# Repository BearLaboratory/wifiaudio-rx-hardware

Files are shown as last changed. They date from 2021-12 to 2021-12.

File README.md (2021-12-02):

<h1 align="center" style="font-size:50px;font-weight:bold">WiFiAudio</h1>
<p align="center">基于WiFi的语音传输系统</p>
<p align="center">
    <a href="https://github.com/">
        
    </a>
    <a href="">
        
    </a> 
    <a href="https://github.com/BruceAKABear">
        
    </a>
</p>

整个系统在组织下分为及个仓库，请根据个人的需求参考：
- [语音发射端硬件](https://github.com/BearLaboratory/wifiaudio-tx-hardware)
- [发射端固件](https://github.com/BearLaboratory/wifiaudio-tx-firmware)
- [接收端硬件](https://github.com/BearLaboratory/wifiaudio-rx-hardware)
- [接收端固件](https://github.com/BearLaboratory/wifiaudio-rx-firmware)
- [PC端接收服务](https://github.com/BearLaboratory/wifiaudio-rx-pc)
- [PCM5102A解码验证模块](https://github.com/BearLaboratory/esp32-pcm51202-audio-hardware)

整个系统所使用的到的工具；
- [EDA工具使用开源免费的Kicad](https://www.kicad.org/)
- [固件开发使用简单的Arduino](https://www.arduino.cc/)

# 1. WiFi Audio RX （基于WiFi的无线麦克风接收端硬件）

WiFi Audio项目的目的是DIY一个开源且便宜的无线麦克风，辅助自己在拍摄视频时的收音。项目有几个根本点：
- 软件键全开源，方便大家对软硬件部分进行针对性的修改；
- 整体成本尽量低，为了达到这个目的在硬件设计部分，我舍弃了很多锦上添花的硬件（比如屏幕）；
- 基于WiFi，由于我个人想让麦克风能接入网络，因此抛弃了传统的UHF转而投入了WiFi的怀抱，正巧这两年芯片价格飞涨唯一还算正常的是上来乐鑫的ESP32系列芯片，价格便宜功能强大具有WiFi及蓝牙功能，因此选择它作为我们麦克的核心处理芯片。

麦克风选择我直接抛弃了传统模拟麦克风，虽然价格便宜，但是其外围电路较复杂，电路对声音音质的影响较大，不适合我们DIY。麦克风我测试的有两款一个是inmp441另一款是ics43434，后者是前者的替代品拥有更高的信噪比，我个人十分推荐使用ics43434。当然还有其他麦克风，奈何我自己没有买来测试，如果有小伙伴有自行测试，请将测试结果反馈给我 <mail>dengyi@dengyi.pro</mail>

# 2. 如何自行打板

整个硬件部分已完整打板测试，如果你使用嘉立创下单助手，直接将gebber目录下压缩文件上传即可，我推荐板材厚度选择1,1.6厚度过大，平时自己焊接过程中加热较麻烦。

如果你使用嘉立创smt服务时，上传坐标文件及bom_lc bom清单即可，如果出现错误，你需要手动去调整原件的方向等，确保焊盘准确即可，bom本身无任何问题。

# 2. 如何上传固件

固件部分，请参考其他仓库。对于固件我都是使用arduino进行编写，因此你需要安装arduino IDE，然后克隆固件仓库，然后进行编译上传。

需要特殊说明：因为我想尽量控制设备成本，所以没有板载烧录电路。进行固件的烧写需要使用我之前开发的ESP系列芯片烧录工具，具体的信息请参见这个仓库[ESP系列芯片烧录工具](https://github.com/BearLaboratory/downloader)

# 3. 如何使用

对于如何使用这部分，我推荐大家反复观看我的项目视频。因为我个人精力有限，每次readme文档我都写的比较糙（虽然多次召集负责写readme的小伙伴，但是并未成功）
# 4. 其他

整个项目在GPL协议下开源，禁止商用，商用请联系<mail>dengyi@dengyi.pro</mail>。

组织下所有开源项目均为个人出于兴趣进行开发及维护，并没有任何盈利，所以在维护频率上可能有很大的延迟，如果小伙伴们有兴趣可以发送邮件到<mail>dengyi@dengyi.pro</mail>与我个人联系或参与到开发中。同时非常欢迎对我的视频频道进行点赞或者关注，[B站](https://space.bilibili.com/402729300),[知乎](https://www.zhihu.com/people/deng-yi-92-16/columns),[youtube](https://www.youtube.com/channel/UCXvLKESzLbINYVe9J8rXerQ)

硬件可以个人自行在嘉立创下单打板，如果需要成品请直接在咸鱼搜索用户**BLab大熊实验室**，由于是非职业卖家，快递费由系统自行计算我做不了主还请谅解。

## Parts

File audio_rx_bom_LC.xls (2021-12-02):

Comment型号 | Designator位号 | Footprint封装 | 嘉立创元件编号(可不要此列)
1uf | C1, | 0402 | C29266
2.2nf | C13,C12, | 0402 | C1531
2.2uf | C16,C14, | 0402 | C12530
10uf | C5,C4,C6,C3,C11, | 0402 | C315248
0.1uf | C7,C2,C15,C10,C9,C8, | 0402 | C1525
LED-red | D1, | 0402 | C165980
LED-green | D4,D3,D2, | 0402 | C165977
Conn_01x03_Female | J2, | 卧贴P=1.25mm | C225126
470Ω | R19,R12,R13,R11,R10,R9, | 0402 | C114877
1k | R16,R15,R8,R6, | 0402 | C106235
5.1k | R2,R1, | 0402 | C25905
10k | R4,R3,R18,R17, | 0402 | C25744
0Ω | R14, | 0805 | C17477
0.4Ω | R5, | 0402 | C728428
1.2k | R7, | 0402 | C25862
SW_Push | SW2, | SMD,3x4x2mm | C720477
ESP-32S | U1, | SMD | C328062
PCM5102 | U2, | TSSOP-20 | C107671
tp4056 | U3, | ESOP-8 | C725790
AMS1117-3.3 | U4, | SOT-223 | C347222
AudioJack4 | J1, | SMD | C95562
USB_C_Receptacle_USB2.0 | J6, | 8.94*7.3mm | C165948
SW_DPDT_x2 | SW1, | SMD | C431540

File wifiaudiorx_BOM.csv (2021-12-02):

Comment | Description | Designator | Footprint | LibRef | Pins | Quantity | PartNumber | url
1uf | desc | C1, | C_0402_1005Metric | libref | 2 | 1
2.2nf | desc | C13,C12, | C_0402_1005Metric | libref | 2 | 2
2.2uf | desc | C16,C14, | C_0402_1005Metric | libref | 2 | 2
10uf | desc | C5,C4,C6,C3,C11, | C_0402_1005Metric | libref | 2 | 5
0.1uf | desc | C7,C2,C15,C10,C9,C8, | C_0402_1005Metric | libref | 2 | 6
LED-red | desc | D1, | D_0402_1005Metric | libref | 2 | 1
LED-green | desc | D4,D3,D2, | D_0402_1005Metric | libref | 2 | 3
Conn_01x03_Female | desc | J2, | JST_GH_SM03B-GHS-TB_1x03-1MP_P1.25mm_Horizontal | libref | 5 | 1
Conn_01x01_Female | desc | J7, | largepoint | libref | 1 | 1
0 | desc | R14, | R_0805_2012Metric | libref | 2 | 1
1k | desc | R16,R15,R8,R6, | R_0402_1005Metric | libref | 2 | 4
470 | desc | R19,R12,R13,R11,R10,R9, | R_0402_1005Metric | libref | 2 | 6
5.1k | desc | R2,R1, | R_0402_1005Metric | libref | 2 | 2
10k | desc | R4,R3,R18,R17, | R_0402_1005Metric | libref | 2 | 4
0.4 | desc | R5, | R_0402_1005Metric | libref | 2 | 1
1.2k | desc | R7, | R_0402_1005Metric | libref | 2 | 1
SW_Push | desc | SW2, | bt-342 | libref | 2 | 1
ESP-32S | desc | U1, | ESP32-WROOM-32 | libref | 39 | 1
pcm5102a | desc | U2, | TSSOP-20_4.4x6.5mm_P0.65mm | libref | 20 | 1
tp4056 | desc | U3, | SOIC-8-1EP_3.9x4.9mm_P1.27mm_EP2.29x3mm | libref | 13 | 1
AMS1117-3.3 | desc | U4, | SOT-223-3_TabPin2 | libref | 4 | 1
Conn_01x01_Female | desc | J5,J4, | largepoint | libref | 1 | 2
Through Hole Items
AudioJack4 | desc | J1, | Jack_3.5mm_PJ320D_Horizontal | libref | 6 | 1
USB_C_Receptacle_USB2.0 | desc | J6, | USB_C_Receptacle_HRO_TYPE-C-31-M-12 | libref | 22 | 1
Conn_01x06_Female | desc | J8, | PinHeader_1x06_P2.00mm_Vertical | libref | 6 | 1
SW_DPDT_x2 | desc | SW1, | SW_SPDT_PCM12 | libref | 9 | 1

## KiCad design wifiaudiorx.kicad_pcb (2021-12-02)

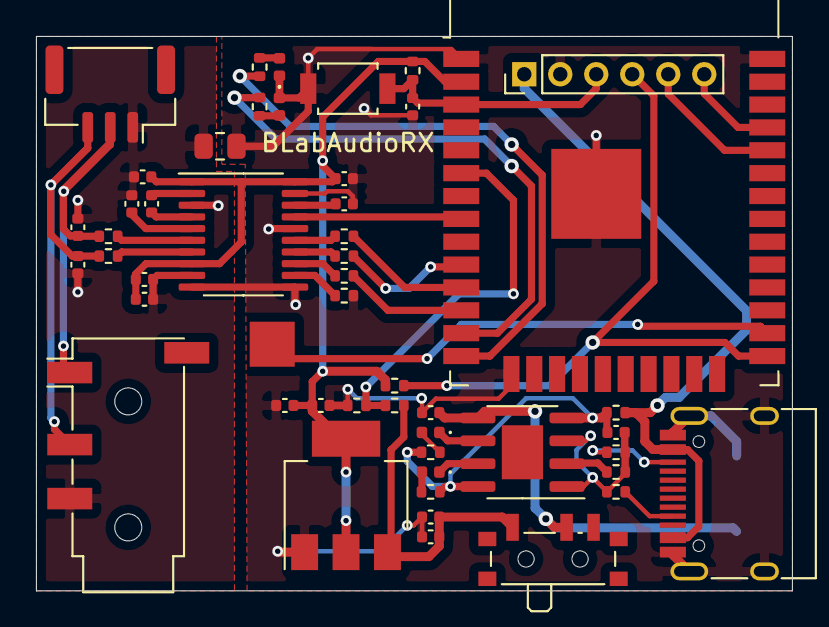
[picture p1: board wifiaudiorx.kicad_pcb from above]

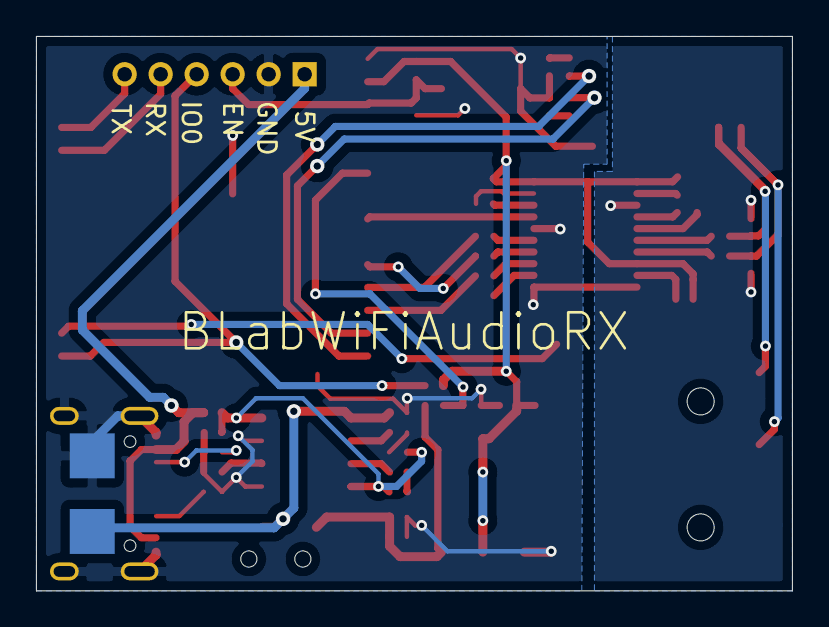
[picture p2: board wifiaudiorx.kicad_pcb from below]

Board: 2 copper layers, 42.0 x 30.8 mm, 52 parts (2 on the bottom side), 40 nets.

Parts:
C1: 1uf; C_0402_1005Metric
C2, C7, C8, C9, C10, C15: 0.1uf; C_0402_1005Metric
C3, C4, C5, C6, C11: 10uf; C_0402_1005Metric
C12, C13: 2.2nf; C_0402_1005Metric
C14, C16: 2.2uf; C_0402_1005Metric
D1: LED-red; D_0402_1005Metric
D2, D3, D4: LED-green; D_0402_1005Metric
J1: AudioJack4; Jack_3.5mm_PJ320D_Horizontal
J2: Conn_01x03_Female; JST_GH_SM03B-GHS-TB_1x03-1MP_P1.25mm_Horizontal
J4, J5, J7: Conn_01x01_Female; largepoint
J6: USB_C_Receptacle_USB2.0; USB_C_Receptacle_HRO_TYPE-C-31-M-12
J8: Conn_01x06_Female; PinHeader_1x06_P2.00mm_Vertical
R1, R2: 5.1k; R_0402_1005Metric
R3, R4, R17, R18: 10k; R_0402_1005Metric
R5: 0.4; R_0402_1005Metric
R6, R8, R15, R16: 1k; R_0402_1005Metric
R7: 1.2k; R_0402_1005Metric
R9, R10, R11, R12, R13, R19: 470; R_0402_1005Metric
R14: 0; R_0805_2012Metric
SW1: SW_DPDT_x2; SW_SPDT_PCM12
SW2: SW_Push; bt-342
U1: ESP-32S; ESP32-WROOM-32
U2: pcm5102a; TSSOP-20_4.4x6.5mm_P0.65mm
U3: tp4056; SOIC-8-1EP_3.9x4.9mm_P1.27mm_EP2.29x3mm
U4: AMS1117-3.3; SOT-223-3_TabPin2

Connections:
+3V3: C3.1, C7.1, C8.2, C9.1, C10.1, C11.2, R3.1, R4.2, U1.2, U2.1, U2.8, U2.20, U4.2
+5V: J6.A4, J6.A9, J6.B4, J6.B9, J8.1, R5.2
ADC: R17.2, R18.1, U1.6
BAT: C5.1, J4.1, SW1.2, U3.5
BCK: R9.1, U1.12
DOUT: R10.2, U1.10
EN: C1.1, J8.3, R3.2, SW2.2, U1.3
GND: C1.2, C2.2, C3.2, C4.2, C5.2, C6.2, C7.2, C10.2, C15.1, D3.1, D4.1, J5.1, J6.A1, J6.A12, J6.B1, J6.B12, J6.S1, J8.2, R1.1, R2.1, R7.2, R14.1, R17.1, R19.1, SW2.1, U1.1, U1.15, U1.38, U1.39, U2.10, U2.11, U2.16, U2.19, U3.1, U3.3, U4.1
GNDA: C8.1, C9.2, C11.1, C12.1, C13.1, C16.2, J1.R2, J2.1, R14.2, U2.3, U2.9
IO0: J8.4, R4.1, U1.25
LRCK: R11.1, U1.11
MUTE: U1.8, U2.17
unnamed: C2.1, C6.1, R18.2, SW1.1, U4.3
unnamed: C4.1, R5.1, R6.2, R8.2, U3.4, U3.8
unnamed: C14.1, U2.2
unnamed: C14.2, U2.4
unnamed: C15.2, U2.18
unnamed: C16.1, U2.5
unnamed: D1.1, U3.7
unnamed: D1.2, R6.1
unnamed: D2.1, U3.6
unnamed: D2.2, R8.1
unnamed: D3.2, R15.1
unnamed: D4.2, R16.1
unnamed: J6.A5, R1.2
unnamed: J6.B5, R2.2
unnamed: J7.1, U1.26
unnamed: R7.1, U3.2
unnamed: R9.2, U2.13
unnamed: R10.1, U2.14
unnamed: R11.2, U2.15
unnamed: R12.1, U2.6
unnamed: R13.1, U2.7
unnamed: R15.2, U1.13
unnamed: R16.2, U1.14
unnamed: R19.2, U2.12
OL: C12.2, J1.T, J2.2, R12.2
OR: C13.2, J1.R1, J2.3, R13.2
RXD: J8.5, U1.34
TXD: J8.6, U1.35

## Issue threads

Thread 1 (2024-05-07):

esp32型号问题

mcu666, 2024-05-07:
bom文档中显示wifi模组为ESP-32S，立创商城编号C328062，但搜索编号C328062显示型号为[ESP32-WROOM-32U-N4](https://item.szlcsc.com/308124.html)，B站视频中我看着是ESP-32S，淘宝优信家两种型号的模组都有，请问型号应该是哪个？
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

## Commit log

2021-12-02 add bom lc
    [audio_rx_bom_LC.xls]
2021-12-02 修改readme

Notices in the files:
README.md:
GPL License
